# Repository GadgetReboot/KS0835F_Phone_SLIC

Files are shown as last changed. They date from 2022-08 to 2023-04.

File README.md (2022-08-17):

# KS0835F_Phone_SLIC
KS0835F phone line SLIC module breakout pcb<br><br>
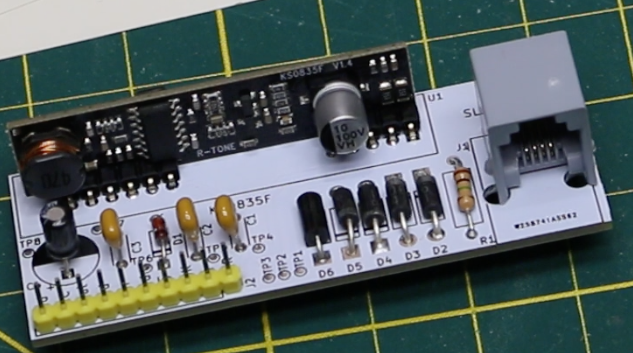
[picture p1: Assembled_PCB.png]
pcb
<br><br>
This pcb includes the recommended support circuitry for the subscriber line interface and provides an RJ phone jack, and a header for providing power, control I/O, and audio in/out.<br><br>
The RJ phone jack used on this PCB is from AliExpress and uses this footprint<br><br>
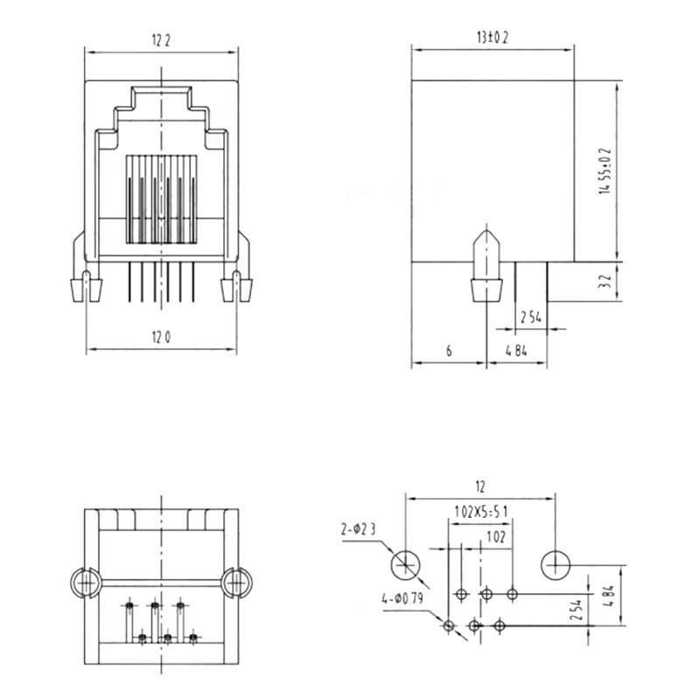
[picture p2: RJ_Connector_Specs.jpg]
RJ


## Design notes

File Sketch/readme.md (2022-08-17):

Demo sketch to generate a ring voltage when a button is pressed, and detect DTMF tones when a phone is off hook.<br>
DTMF detection makes use of the MT8870 breakout board https://github.com/GadgetReboot/DTMF_Decoder

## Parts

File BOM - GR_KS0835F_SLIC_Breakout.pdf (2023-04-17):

KS0835F SLIC Module BOM

Item # | Reference Designator | Qty | Manufacturer | Mfg Part # | Description / Value | Package/Footprint | Type | Instructions / Notes
1 | C1 C2 C3 | 3 | Vishay | K104K15X7RF5TH5 | 0.1 µF ±10% 50V Ceramic Capacitor X7R Radial | 5mm Pitch | THRU-HOLE
2 | C4 | 1 | Panasonic | ECE-A1CKS100B | CAP ALUM 10UF 20% 16V RADIAL | 5mm Pitch | THRU-HOLE
3 | D2 D3 D4 D5 | 4 | Onsemi | 1N4004 | DIODE GEN PURP 400V 1A DO41 | DO-41 | THRU-HOLE
4 | D1 | 1 | Onsemi | 1N4148 | DIODE GEN PURP 100V 200MA DO35 | DO-35 | THRU-HOLE
5 | D6 | 1 | Littelfuse | P6KE82A | TVS DIODE 70.1VWM 113VC | DO-15 | THRU-HOLE
6 | J2 | 1 | Sullins Connector Solutions | PREC010SAAN-RC | CONN HEADER VERT 10POS 2.54MM | 10POS | THRU-HOLE
7 | J1 | 1 | Ckmtw(Shenzhen Cankemeng) | R-RJ11R06P-A800 | RJ11 RJ Receptacle Modular Connector | 6POS | THRU-HOLE
8 | R1 | 1 | YAGEO | CFR-25JR-52-1M | RES 1M OHM 5% 1/4W AXIAL | Axial | THRU-HOLE
9 | U1 | 1 | Shenzhen Ring&Tone | KS0835F | RING Subscriber Line Interface Circuit Module | SIP Special | THRU-HOLE | Purchased from AliExpress. Manufacturer: http://www.r-tone.com/contact-us

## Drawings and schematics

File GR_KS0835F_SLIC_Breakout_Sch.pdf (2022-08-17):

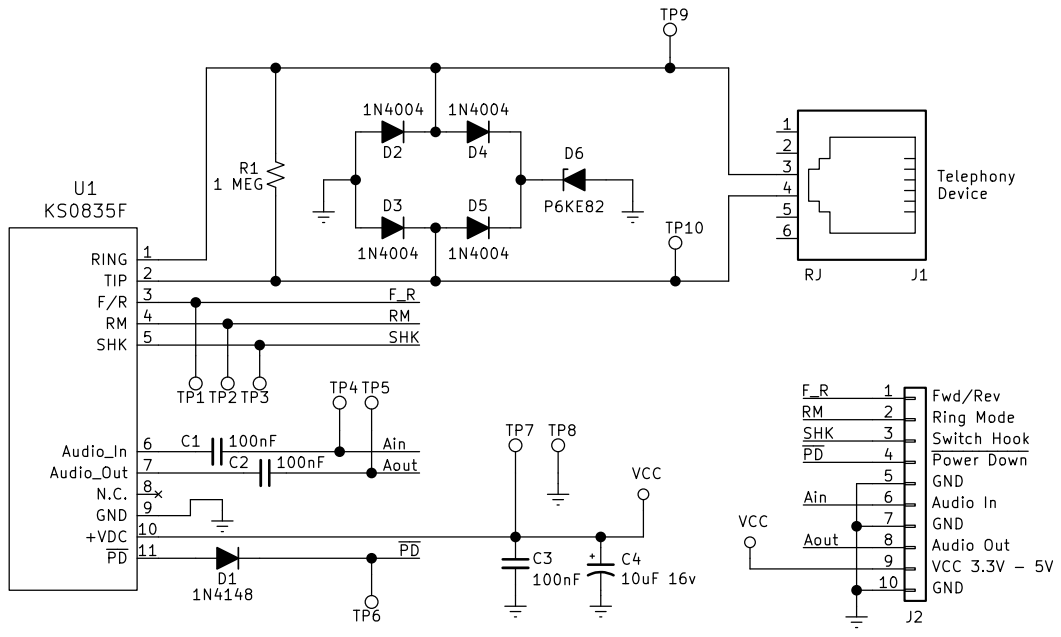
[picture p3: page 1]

https://github.com/GadgetReboot/KS0835F_Phone_SLIC
https://www.youtube.com/gadgetreboot
File: GR_KS0835F_SLIC_Breakout.sch Sheet: / Gadget Reboot

Id: 1/1 Title: KS0835F SLIC Breakout

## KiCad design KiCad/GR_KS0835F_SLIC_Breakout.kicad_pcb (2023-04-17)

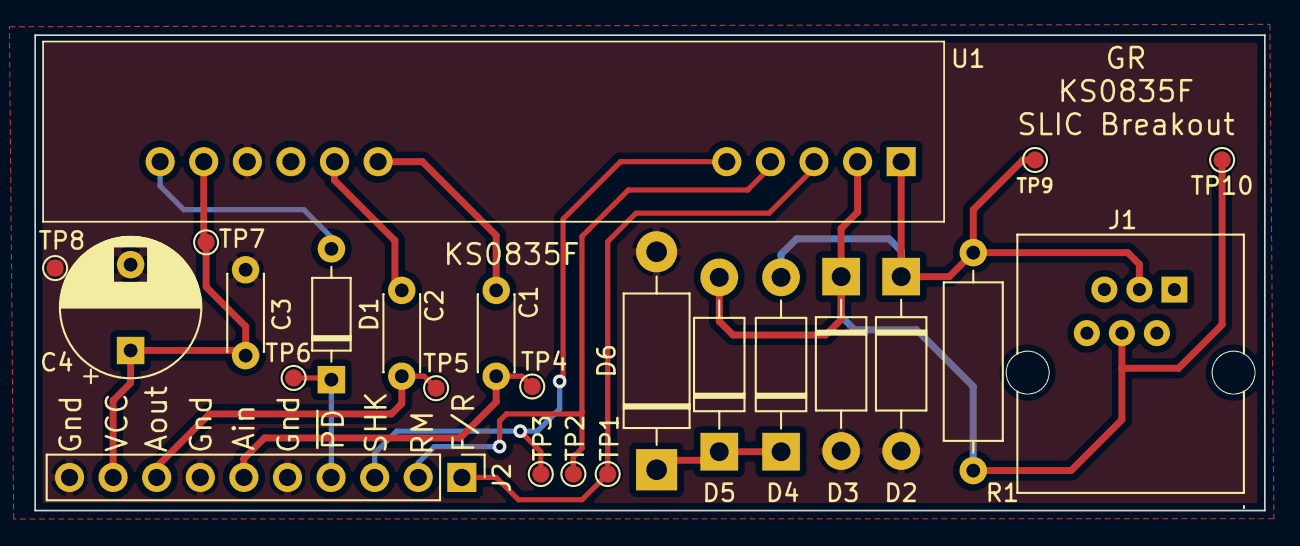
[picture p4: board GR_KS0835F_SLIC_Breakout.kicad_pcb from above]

Board: 2 copper layers, 71.7 x 27.7 mm, 24 parts (0 on the bottom side), 14 nets.

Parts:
C1, C2, C3: 100nF; C_Disc_D4.3mm_W1.9mm_P5.00mm
C4: 10uF 16v; CP_Radial_D8.0mm_P5.00mm
D1: 1N4148; D_DO-35_SOD27_P7.62mm_Horizontal
D2, D3, D4, D5: 1N4004; D_DO-41_SOD81_P10.16mm_Horizontal
D6: P6KE82; D_DO-15_P12.70mm_Horizontal
J1: RJ; RJ_6p6c
J2: Conn_01x10; PinHeader_1x10_P2.54mm_Vertical
R1: 1 MEG; R_Axial_DIN0309_L9.0mm_D3.2mm_P12.70mm_Horizontal
TP1, TP2, TP3, TP4, TP5, TP6, TP7, TP8, TP9, TP10: TestPoint; TestPoint_Pad_D1.0mm
U1: KS0835F

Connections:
/Ain: C1.1, J2.6, TP4.1
/Aout: C2.1, J2.8, TP5.1
/F_R: J2.1, TP1.1, U1.3
/RM: J2.2, TP2.1, U1.4
/SHK: J2.3, TP3.1, U1.5
/~PD: D1.1, J2.4, TP6.1
GNDREF: C3.2, C4.2, D2.2, D3.2, D6.2, J2.5, J2.7, J2.10, TP8.1, U1.9
unnamed: C1.2, U1.6
unnamed: C2.2, U1.7
unnamed: D1.2, U1.11
unnamed: D2.1, D4.2, J1.3, R1.2, TP9.1, U1.1
unnamed: D3.1, D5.2, J1.4, R1.1, TP10.1, U1.2
unnamed: D4.1, D5.1, D6.1
VCC: C3.1, C4.1, J2.9, TP7.1, U1.10

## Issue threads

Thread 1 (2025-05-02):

Lib file is missing (KiCAD)

MatsK, 2025-05-02:
KiCAD is complaining that the file `GR_KS0835F_SLIC_Breakout-cache.lib` is missing.

When opening the KiCAD project in KiCAD 8/9 it complains that the lib file is missin.

MatsK, 2025-05-03:
Thx that made it!

MatsK, 2025-05-03:
Oops, I think something got wrong.
I just open the schema and noticed that the "warning" was gone and then I closed this issue.
Then I opened the schema again and noticed it is the wrong schema, it is "ATTiny 14 pin 0-Series and 1-Series USB Breakout" but the PCB is the SLIC one.

GadgetReboot, 2025-05-03:
That's weird, I confirmed now it's the wrong schematic so again I re-opened the same original old one and re-saved it in version 9 and now it looks right, so no idea why that occurred.
Maybe it's because I originally started the design by editing that different project and maybe there's an undo history in the file that the converter accidentally rolled back to.
Try again!

MatsK, 2025-05-03:
Thx. works as a charm.

Closed 2025-05-03.

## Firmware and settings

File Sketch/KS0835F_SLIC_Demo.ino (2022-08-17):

// KS0835F phone line interface SLIC and MT8870 DTMF Decoder Demo
// Target Hardware:  Uno, SLIC breakout board, DTMF Decoder board
// https://github.com/GadgetReboot/DTMF_Decoder
// https://github.com/GadgetReboot/KS0835F_Phone_SLIC
//
// MT8870 Pin         Uno Pin
//   Q1                  2
//   Q2                  3
//   Q3                  4
//   Q4                  5
//   StD                 6
//
// KS0835F pin        Uno Pin
//   F_R                 7
//   RM                  8
//   SHK                 9
//
//  Ring push button     10
//
// When the ring button is pressed, if the phone is on-hook (required for ringing a phone),
// a 20 Hz ring signal is generated.
//
// When the phone is taken off-hook, any DTMF signals are decoded and printed on the serial monitor.
//
// Tested with Arduino IDE 1.8.13
// Gadget Reboot
// https://www.youtube.com/gadgetreboot

// input pins from MT8870
const byte Q1 = 2;    // dtmf data bits to decode
const byte Q2 = 3;
const byte Q3 = 4;
const byte Q4 = 5;
const byte StD = 6;   // delayed steering = high when valid Q1..Q4 data present

// pins for KS0835F module interface
const byte F_R = 7;   // forward/reverse is toggled to produce ringing output, set low for other modes
const byte  RM = 8;   // set high while generating a ring output, low for other modes
const byte SHK = 9;   // switch hook input is high to indicate an off-hook condition, low for on-hook

const byte ringButton = 10;  // button to generate a ring signal on the phone line

byte hookStatus = 1;  // track whether phone is on or off hook (0=off-hook 1=on-hook)

void setup() {
  Serial.begin(9600);

  // configure MT8870 pins
  pinMode(Q1, INPUT);
  pinMode(Q2, INPUT);
  pinMode(Q3, INPUT);
  pinMode(Q4, INPUT);
  pinMode(StD, INPUT);

  // configure KS0835F pins
  pinMode(F_R, OUTPUT);
  pinMode(RM, OUTPUT);
  pinMode(SHK, INPUT);

  pinMode(ringButton, INPUT_PULLUP);  // button to ring the phone

  Serial.println();
  Serial.println("KS0835F SLIC and MT8870 DTMF Decoder Demo");
  Serial.println();

}

void loop() {

  // ensure module is configured so KS0835F control pins
  // are set for non ringing standby mode at the start of each loop
  digitalWrite(F_R, LOW);  // set forward/reverse pin low for all modes except ringing
  digitalWrite(RM, LOW);   // set ring mode pin low for all modes except ringing

  // check if phone hook status has changed (just picked up or placed back on-hook)
  byte reading = digitalRead(SHK);
  if (reading != hookStatus) {
    if (hookStatus == 0)
      Serial.println("Phone is OFF hook...");
    else
      Serial.println("Phone is ON hook...");
    hookStatus = reading;
    delay(20);  // crude and vile "debounce" delay because KS0835F hook signal needs debouncing
  }

  // generate a short ring signal if button is pressed
  if (!digitalRead(ringButton)) {
    generateRingSignal();
  }

  // if phone is off hook, listen for DTMF tones
  if (digitalRead(SHK)) {
    checkDTMF();  // see if there has been a DTMF keypress and print on serial monitor if so
  }

}

// generate a test ring signal
void generateRingSignal() {
  // check if phone is on-hook before ringing, then generate a short ring at 20 Hz
  // this should be implemented better, maybe with interrupts so that as soon as the
  // phone is picked up, ring generation stops but this is ok for testing
  if (!digitalRead(SHK)) {
    Serial.println("Ringing phone...");
    digitalWrite(RM, HIGH);         // enable ring mode
    for (int i = 0; i < 40; i++) {
      digitalWrite(F_R, HIGH);      // toggle fwd/rev pin to generate ring
      delay(25);  // 25 mS = half of 20 Hz period
      digitalWrite(F_R, LOW);
      delay(25);  // 25 mS = half of 20 Hz period
    }
    digitalWrite(RM, LOW);          // disable ring mode
  }
}

// check if there is a valid DTMF signal to decode
void checkDTMF() {
  // StD (delayed steering) output from MT8870 is high while a DTMF signal is present, low when not
  // when a DTMF tone pair is present, decode the key pressed (0-9, *, #)  A, B, C, D  are not decoded
  if (digitalRead(StD)) {
    uint8_t dtmf = ( 0x00 | (digitalRead(Q1) << 0) | (digitalRead(Q2) << 1) | (digitalRead(Q3) << 2) | (digitalRead(Q4) << 3) );
    switch (dtmf)
    {
      case 0x01:
        Serial.println("DTMF: 1");
        break;
      case 0x02:
        Serial.println("DTMF: 2");
        break;
      case 0x03:
        Serial.println("DTMF: 3");
        break;
      case 0x04:
        Serial.println("DTMF: 4");
        break;
      case 0x05:
        Serial.println("DTMF: 5");
        break;
      case 0x06:
        Serial.println("DTMF: 6");
        break;
      case 0x07:
        Serial.println("DTMF: 7");
        break;
      case 0x08:
        Serial.println("DTMF: 8");
        break;
      case 0x09:
        Serial.println("DTMF: 9");
        break;
      case 0x0A:
        Serial.println("DTMF: 0");
        break;
      case 0x0B:
        Serial.println("DTMF: *");
        break;
      case 0x0C:
        Serial.println("DTMF: #");
        break;
    }
    while (digitalRead(StD)) {};  // wait for current dtmf signal to end before looking for the next one
  }
}
